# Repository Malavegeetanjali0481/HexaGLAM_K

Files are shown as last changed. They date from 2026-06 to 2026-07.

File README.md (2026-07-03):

## 1)🚶 Hexapod Walking

The walking function enables the hexapod robot to move forward using a tripod gait, where three legs move while the other three remain on the ground for support. This gait provides excellent stability, smooth movement, and balanced weight distribution, allowing the robot to navigate different surfaces efficiently while maintaining continuous balance.

Walking Demo Video : https://github.com/Malavegeetanjali0481/HexaGLAM_K/issues/1

## 2)💃 Hexapod Dancing

The dancing function demonstrates the robot's coordinated servo movements by executing a sequence of rhythmic leg motions. The programmed dance routine synchronizes all six legs to create smooth and visually appealing movements, showcasing the precision of the inverse kinematics and servo control system while highlighting the robot's flexibility and stability.

 Dancing Demo Video : https://github.com/Malavegeetanjali0481/HexaGLAM_K/issues/2
 
## 3)📱 HexaGlAM_K Mobile Application Development

The HexaGlAM_K mobile application was developed using MIT App Inventor to provide an intuitive interface for controlling and monitoring the ESP32-based Hexapod Robot. The application consists of multiple screens, each designed for a specific functionality, making robot operation simple and user-friendly.

### Step 1: Designing the Home Screen

The development began by creating the Home Screen, which serves as the application's landing page. A clean and attractive user interface was designed with the project title, robot image/logo, and navigation buttons. This screen allows users to easily access different modules of the application such as Robot Control, Sensor Dashboard, Camera Monitoring, and About sections. Proper alignment, icons, and color themes were chosen to enhance the overall user experience.

### Step 2: Developing the Robot Control Screen

A dedicated Control Screen was developed to operate the Hexapod robot remotely. Large control buttons were added to send Bluetooth commands to the ESP32. Each button transmits a predefined command that controls the robot's movements.

The implemented control functions include:
<ul>
  <li>Stand</li>
   <li>Walk</li>
   <li>Dance</li>
   <li>Halt</li>

</ul>

### Step 3: Creating the Sensor Dashboard

A Sensor Dashboard was developed to display real-time environmental data collected by the sensors connected to the ESP32. The dashboard retrieves data from the ThingSpeak cloud platform and presents all sensor readings on a single screen.
Each sensor value is displayed inside individual cards with appropriate labels, making the dashboard easy to understand and monitor.
### These are the Screens of app:
<table>
  <tr>
    <td >
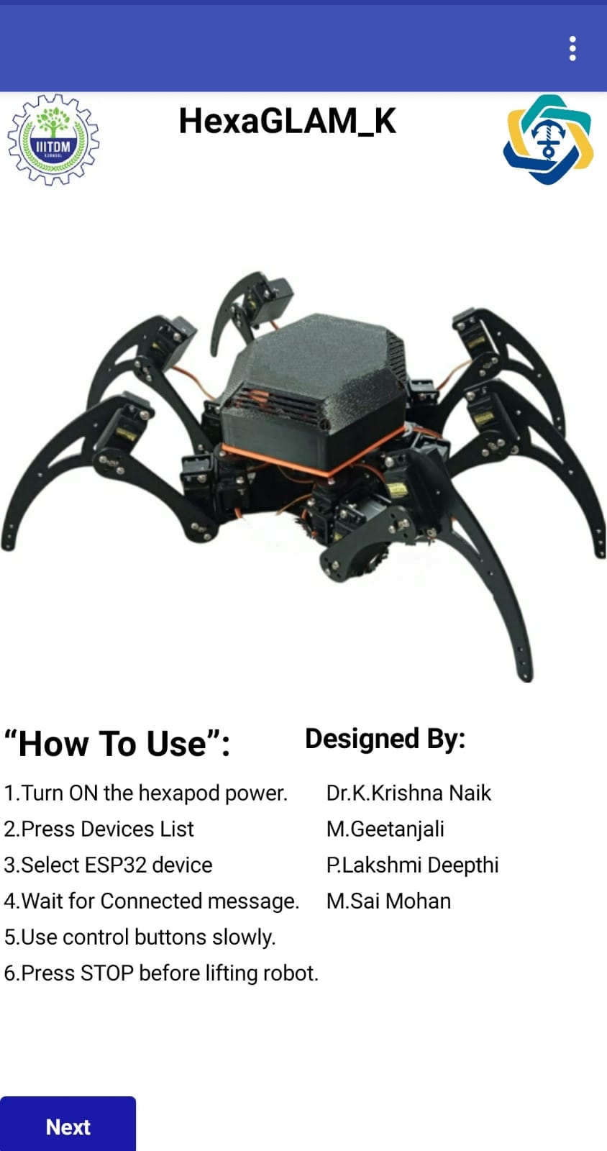
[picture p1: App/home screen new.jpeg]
Home Screen
       
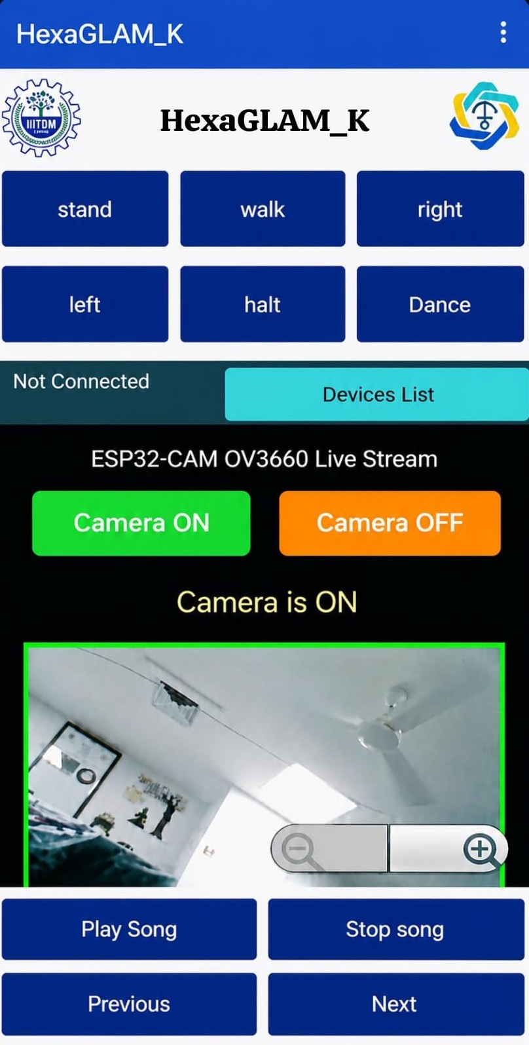
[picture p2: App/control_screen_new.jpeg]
   
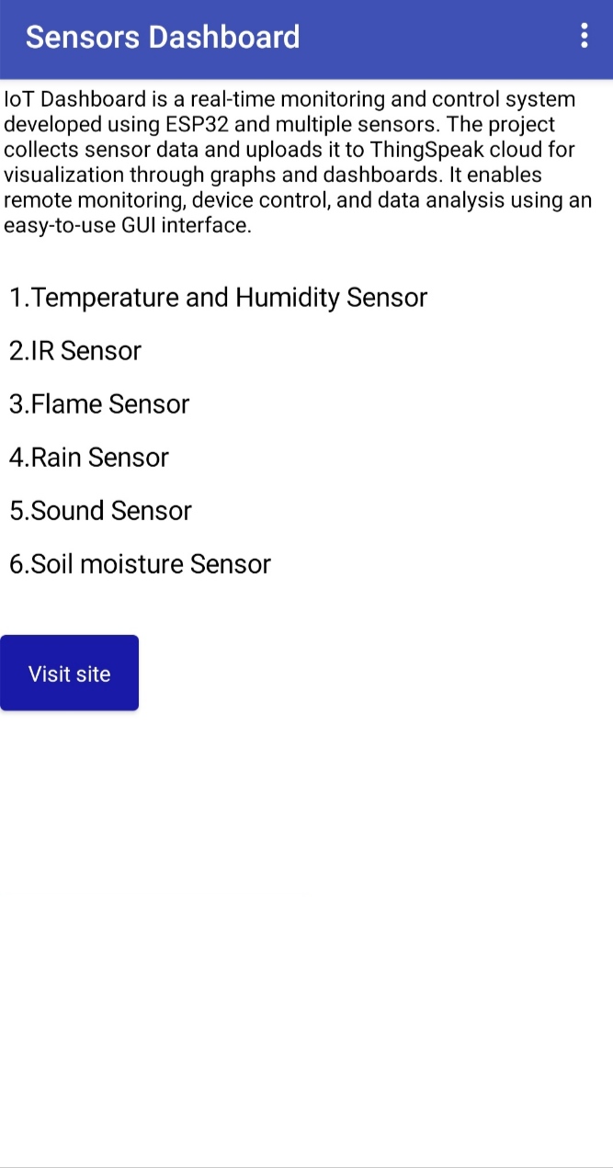
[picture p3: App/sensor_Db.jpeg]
    
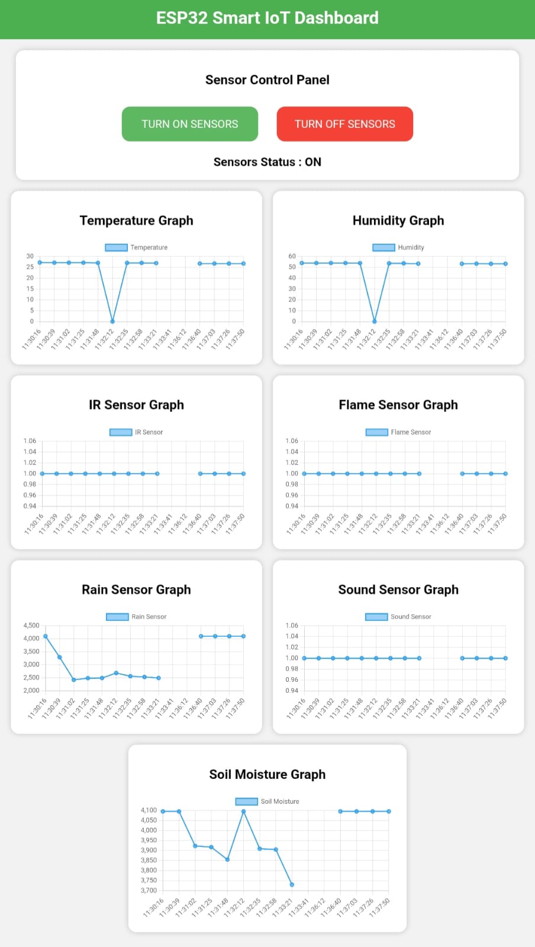
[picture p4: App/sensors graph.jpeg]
     
    </td>
  </tr>
</table>

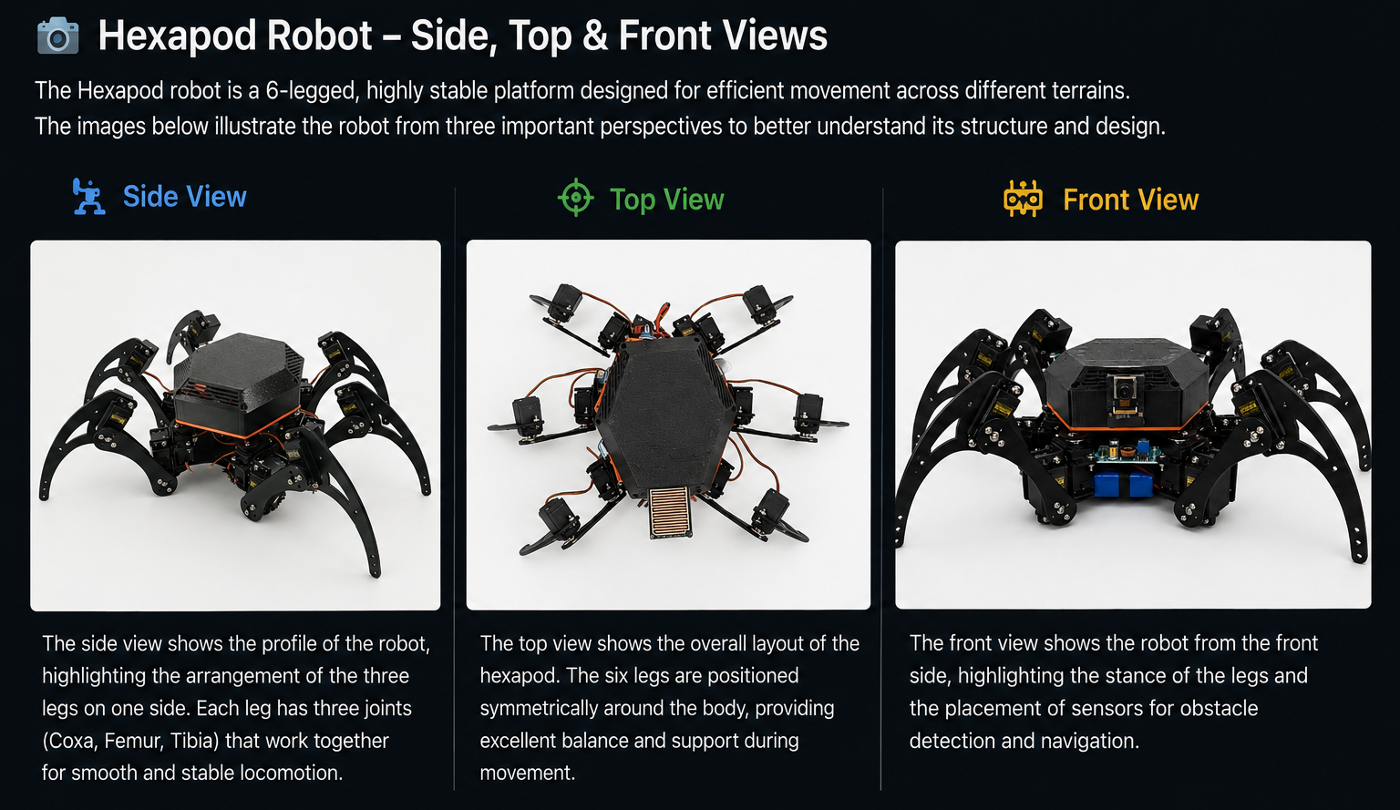
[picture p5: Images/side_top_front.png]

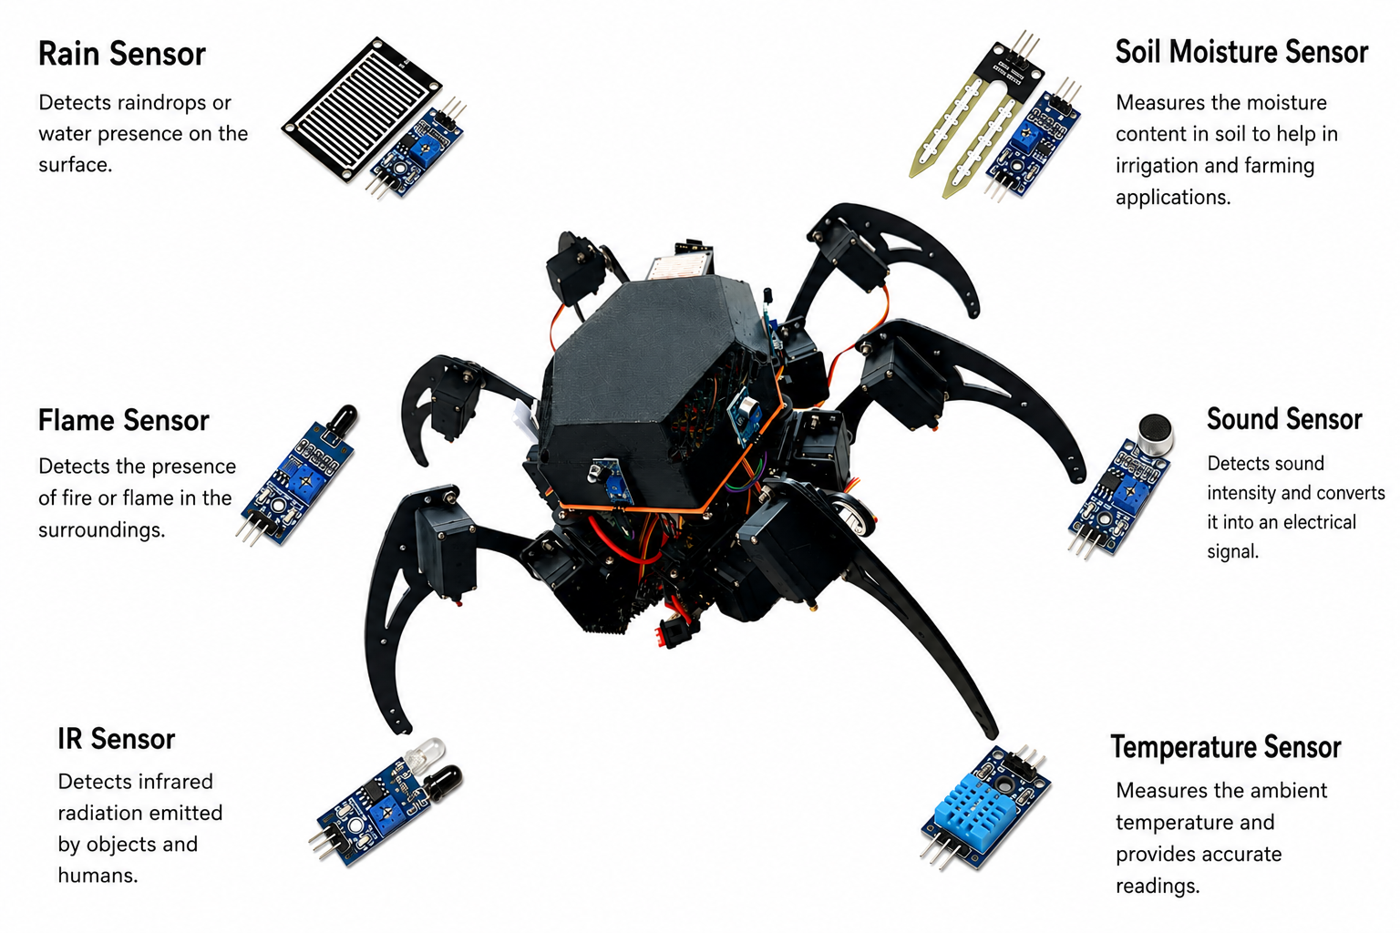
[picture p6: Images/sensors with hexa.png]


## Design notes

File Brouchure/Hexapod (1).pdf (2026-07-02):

# Market analysis

# Implementation strategy

# HEXAPOD WITH

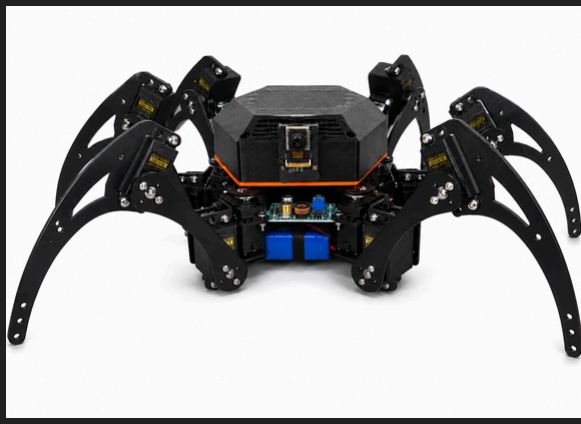
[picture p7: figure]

# SENSORS

## The global market for hexapod robots is growing rapidly across defense, industrial

inspection, agriculture, healthcare, research,

## and disaster response, driven by advancements in robotics, IoT, AI, and

automation.

## The hexapod robot was implemented by

designing the mechanical structure,

## interfacing 18 servo motors with an ESP32 through PCA9685 servo drivers, and integrating sensors for real-time data collection. A Bluetooth-based mobile app was developed for robot control

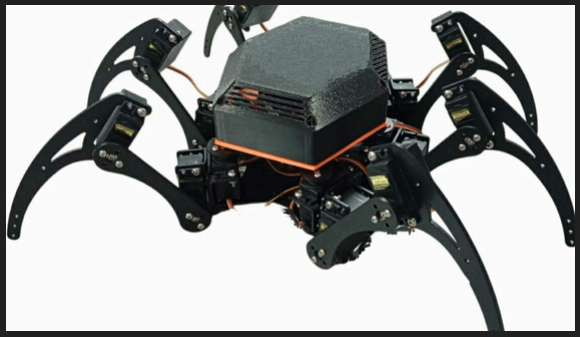
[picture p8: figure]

# Project goals and objectives

## This project presents a Hexapod Robot built using an ESP32 microcontroller and an 18-servo locomotion system. The robot is designed to achieve stable movement

using a six-legged walking mechanism,

## making it suitable for navigating uneven

terrain while maintaining balance.

# Welcome!

# HexaGLAM_K App

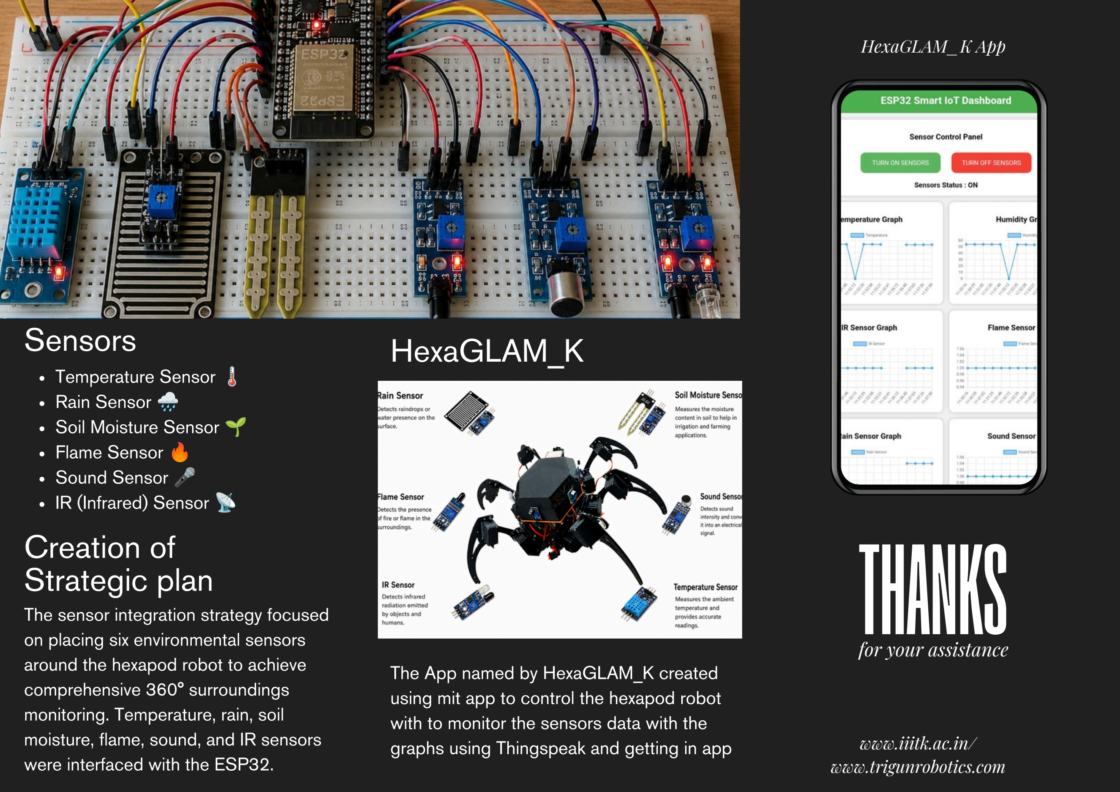
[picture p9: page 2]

# THANKS

The sensor integration strategy focused

on placing six environmental sensors

around the hexapod robot to achieve

comprehensive 360° surroundings

monitoring. Temperature, rain, soil

moisture, flame, sound, and IR sensors

were interfaced with the ESP32.

# Sensors

# Creation of Strategic plan

Temperature Sensor | ️
Rain Sensor | ️
Soil Moisture Sensor 🌱

Flame Sensor 🔥

Sound Sensor 🎤

IR (Infrared) Sensor 📡

# HexaGLAM

_

K

The App named by HexaGLAM_K created

using mit app to control the hexapod robot

with to monitor the sensors data with the

graphs using Thingspeak and getting in app

# for your assistance

# www.iiitk.ac.in/ www.trigunrobotics.com

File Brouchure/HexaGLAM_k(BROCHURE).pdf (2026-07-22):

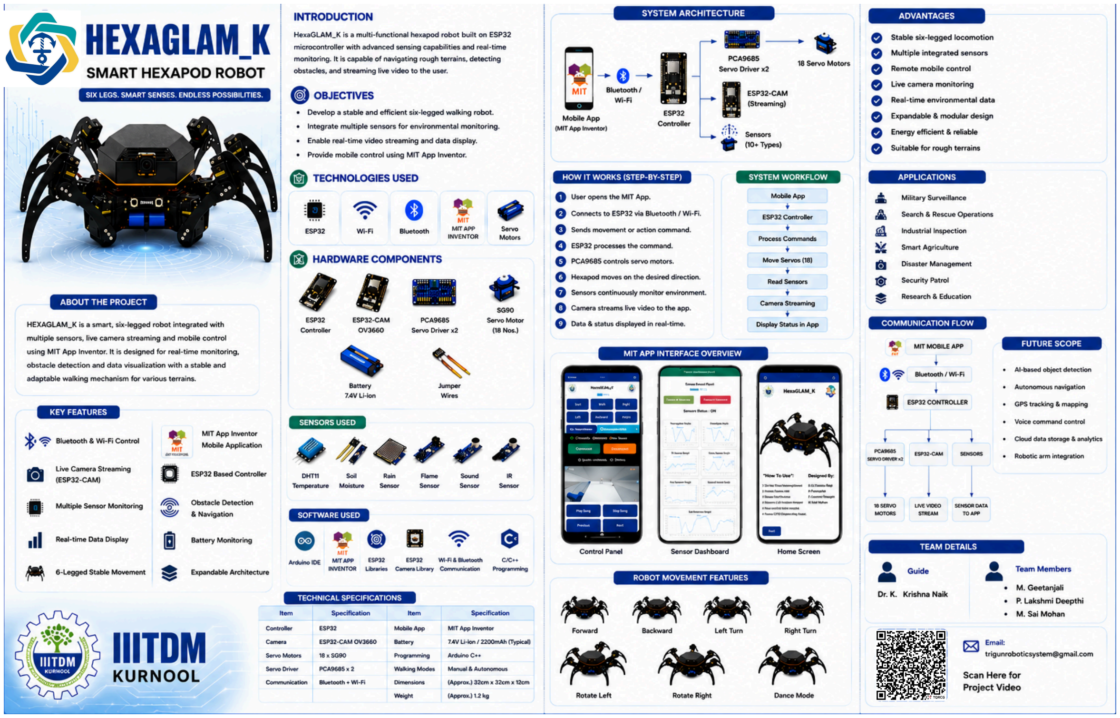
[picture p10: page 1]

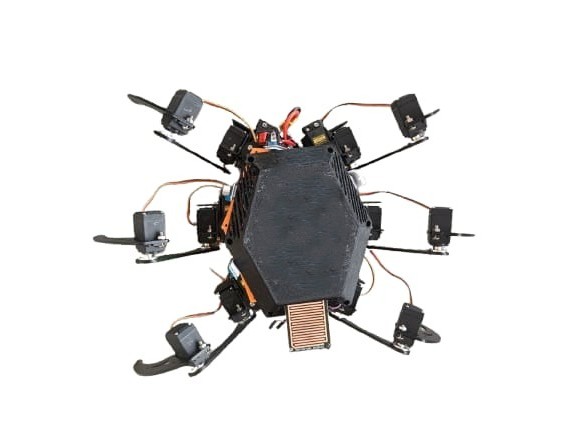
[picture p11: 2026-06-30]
Images/top_view.jpeg

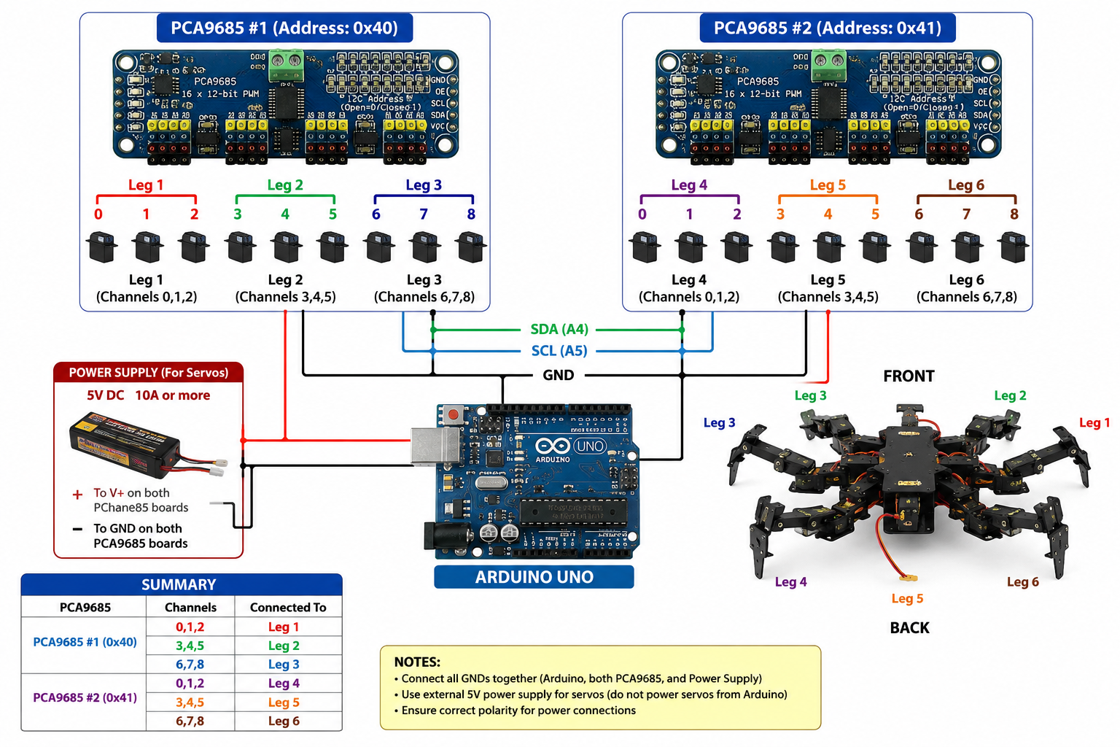
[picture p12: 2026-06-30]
Images/pca connections ant.png

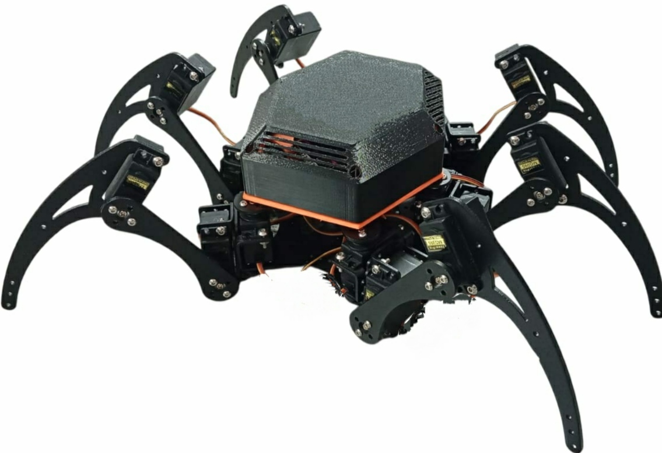
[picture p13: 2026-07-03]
Images/zoom hexapod.jpeg

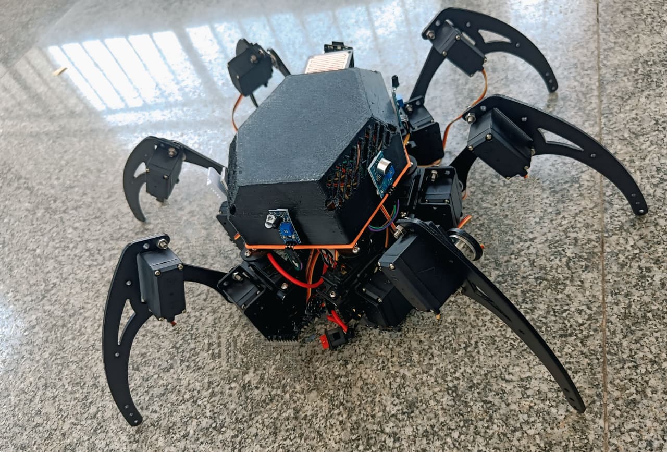
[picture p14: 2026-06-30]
Images/sen___ss.jpeg

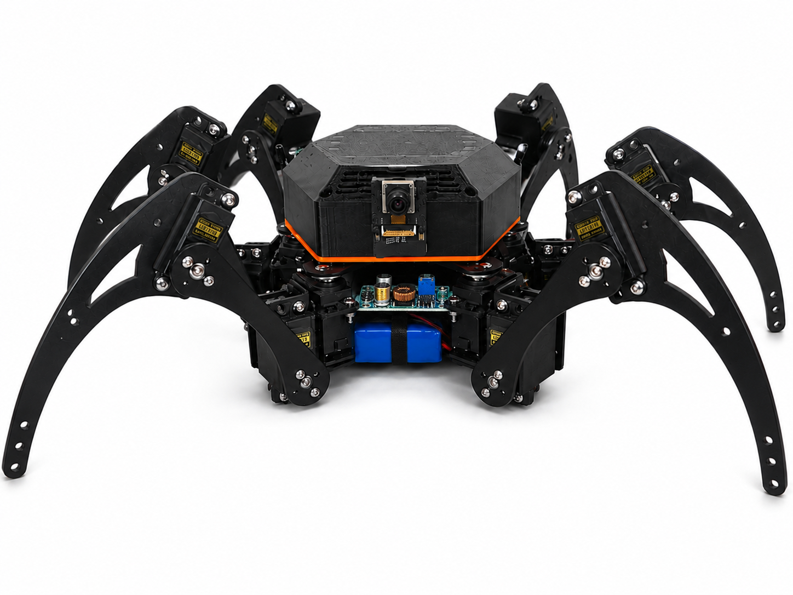
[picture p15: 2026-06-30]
Images/Front view.png

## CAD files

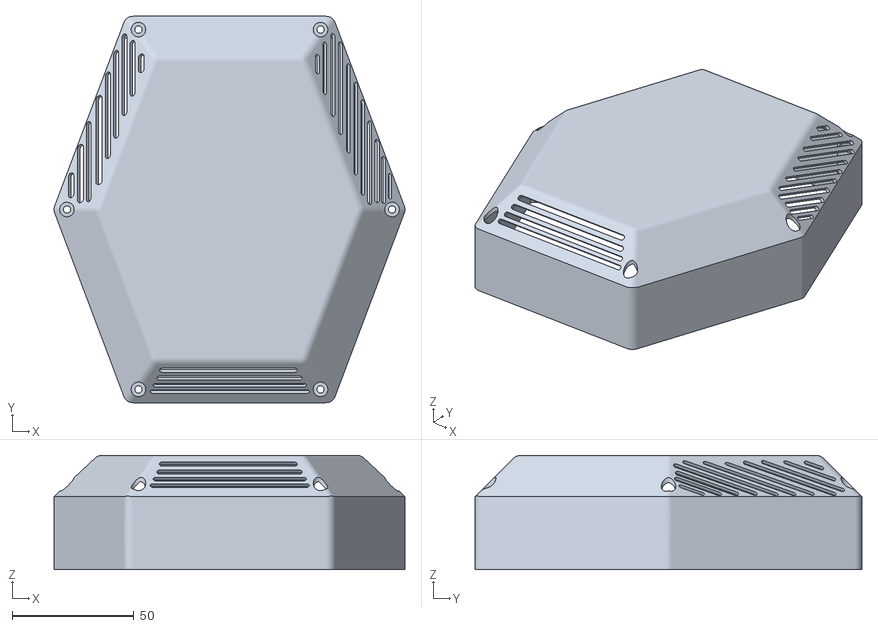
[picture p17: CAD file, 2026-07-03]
Dimension/Part Studio 1 - Top.stl
144.4 x 159.1 x 47.0

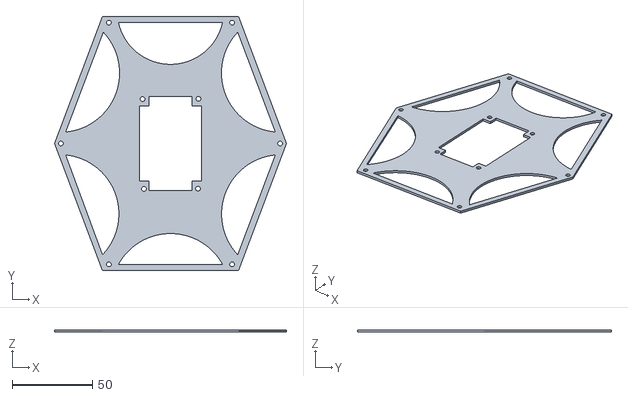
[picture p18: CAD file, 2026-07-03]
Dimension/Part Studio 2 - Base.stl
145.0 x 159.1 x 1.50

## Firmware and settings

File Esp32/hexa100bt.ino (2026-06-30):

#include <Wire.h>
#include <Adafruit_PWMServoDriver.h>

// =====================================================
// BLUETOOTH SUPPORT ADDED
// =====================================================
#include "BluetoothSerial.h"
BluetoothSerial SerialBT;

// =====================================================
// HEXAPOD ROBOT (ESP32 VERSION)
// Logic unchanged from Nano version
// =====================================================

// ------------------- CONFIG -------------------
#define SERVO_FREQ 60

// ESP32 I2C PINS
#define SDA_PIN 21
#define SCL_PIN 22

// ------------------- GAIT PARAMETERS -------------------
float gaitCycleTime = 1600;
float stanceRatio   = 0.65;

// Motion amplitudes
float coxaAmplitude = 15;
float femurLift     = 15;
float tibiaLift     = 8;

// Servo safety limits
int minAngle = 40;
int maxAngle = 150;

// ------------------- JOINT DEFINITIONS -------------------
#define COXA  0
#define FEMUR 1
#define TIBIA 2

// ------------------- LEG DEFINITIONS -------------------
#define FL 0
#define ML 1
#define RL 2
#define FR 3
#define MR 4
#define RR 5

// ------------------- SERVO MAPPING -------------------
int servoIndex[6][3] = {

  {0, 1, 2},
  {3, 4, 5},
  {6, 7, 8},

  {9, 10, 11},
  {12, 13, 14},
  {15, 16, 17}
};

// ------------------- NEUTRAL POSITIONS -------------------
int neutralAngle[6][3] = {

  {130, 70, 70},
  {90, 70, 70},
  {70, 70, 70},

  {70, 105, 130},
  {90, 105, 110},
  {120, 110, 130}
};

// ------------------- INVERSION FLAGS -------------------
int invCoxa[6]  = {-1, -1, -1,  1,  1,  1};

int invFemur[6] = {
   1,  1,  1,
  -1, -1, -1
};

int invTibia[6] = {
   1,  1,  1,
  -1, -1, -1
};

// =====================================================
// PCA9685 OBJECTS
// =====================================================

Adafruit_PWMServoDriver pwm1 = Adafruit_PWMServoDriver(0x40);
Adafruit_PWMServoDriver pwm2 = Adafruit_PWMServoDriver(0x41);

float usPerTick;

// =====================================================
// CONTROL MODES
// =====================================================

enum Mode {
  STAND,
  WALK,
  HALT
};

Mode mode = STAND;

// =====================================================
// TIMERS
// =====================================================

unsigned long gaitStartTime = 0;
unsigned long lastUpdate = 0;

// =====================================================
// UTILITY FUNCTIONS
// =====================================================

uint16_t usToTicks(uint16_t us) {

  float ticks = us / usPerTick;

  if (ticks < 0) ticks = 0;
  if (ticks > 4095) ticks = 4095;

  return (uint16_t)(ticks + 0.5f);
}

// Convert angle -> microseconds
uint16_t angleToUs(int angle) {

  return map(angle, 0, 180, 480, 2120);
}

// =====================================================
// SERVO OUTPUT
// =====================================================

void setServoAngle(int servo, int angle) {

  angle = constrain(angle, minAngle, maxAngle);

  uint16_t us = angleToUs(angle);
  uint16_t ticks = usToTicks(us);

  // PCA BOARD #1
  if (servo < 16) {

    pwm1.setPWM(servo, 0, ticks);
  }

  // PCA BOARD #2
  else {

    pwm2.setPWM(servo - 16, 0, ticks);
  }
}

// =====================================================
// GAIT MATH
// =====================================================

// Smooth lift curve
float liftShape(float local) {

  return sin(local * PI);
}

// Coxa motion
float coxaOffset(float phase) {

  // STANCE
  if (phase < stanceRatio) {

    float local = phase / stanceRatio;

    return -coxaAmplitude * cos(local * PI);
  }

  // SWING
  else {

    float local = (phase - stanceRatio) / (1.0 - stanceRatio);

    return coxaAmplitude * cos(local * PI);
  }
}

// Femur lift
float femurOffset(float phase) {

  if (phase < stanceRatio) {
    return 0;
  }

  float local = (phase - stanceRatio) / (1.0 - stanceRatio);

  return femurLift * liftShape(local);
}

// Tibia lift
float tibiaOffset(float phase) {

  if (phase < stanceRatio) {
    return 0;
  }

  float local = (phase - stanceRatio) / (1.0 - stanceRatio);

  return tibiaLift * liftShape(local);
}

// =====================================================
// PHASE FUNCTIONS
// =====================================================

// Tripod phase assignment
float legPhase(int leg, float globalPhase) {

  bool tripodA =
    (leg == FL || leg == MR || leg == RL);

  float p = globalPhase;

  // Tripod B shift
  if (!tripodA) {
    p += 0.5;
  }

  if (p >= 1.0) {
    p -= 1.0;
  }

  return p;
}

// =====================================================
// ANGLE COMPUTATION
// =====================================================

float computeAngle(int leg, int joint, float phase) {

  float offset = 0;

  // COXA
  if (joint == COXA) {

    offset =
      coxaOffset(phase) *
      invCoxa[leg];
  }

  // FEMUR
  if (joint == FEMUR) {

    offset =
      femurOffset(phase) *
      invFemur[leg];
  }

  // TIBIA
  if (joint == TIBIA) {

    offset =
      tibiaOffset(phase) *
      invTibia[leg];
  }

  return neutralAngle[leg][joint] + offset;
}

// =====================================================
// POSES
// =====================================================

void standPose() {

  for (int leg = 0; leg < 6; leg++) {

    for (int joint = 0; joint < 3; joint++) {

      setServoAngle(
        servoIndex[leg][joint],
        neutralAngle[leg][joint]
      );
    }
  }
}

// =====================================================
// WALKING
// =====================================================

void walkCycle() {

  float cycle =
    (millis() - gaitStartTime) %
    (unsigned long)gaitCycleTime;

  float globalPhase =
    cycle / gaitCycleTime;

  // Update all legs
  for (int leg = 0; leg < 6; leg++) {

    float phase =
      legPhase(leg, globalPhase);

    for (int joint = 0; joint < 3; joint++) {

      int angle =
        computeAngle(
          leg,
          joint,
          phase
        );

      setServoAngle(
        servoIndex[leg][joint],
        angle
      );
    }
  }
}

// =====================================================
// SERIAL + BLUETOOTH COMMANDS
// =====================================================

void handleSerial() {

  String cmd = "";

  // ---------------- SERIAL INPUT ----------------
  if (Serial.available()) {

    cmd =
      Serial.readStringUntil('\n');

    cmd.trim();
  }

  // -------------- BLUETOOTH INPUT ---------------
  else if (SerialBT.available()) {

    cmd =
      SerialBT.readStringUntil('\n');

    cmd.trim();
  }

  else {
    return;
  }

  // ---------------- STAND ----------------
  if (cmd == "s" || cmd == "stand") {

    mode = STAND;

    standPose();

    Serial.println("Mode: STAND");
    SerialBT.println("Mode: STAND");
  }

  // ---------------- WALK ----------------
  else if (cmd == "w" || cmd == "walk") {

    gaitStartTime = millis();

    mode = WALK;

    Serial.println("Mode: WALK");
    SerialBT.println("Mode: WALK");
  }

  // ---------------- HALT ----------------
  else if (cmd == "h" || cmd == "halt") {

    mode = HALT;

    Serial.println("Mode: HALT");
    SerialBT.println("Mode: HALT");
  }

  // ---------------- SPEED ----------------
  else if (cmd.startsWith("speed ")) {

    int value =
      cmd.substring(6).toInt();

    if (value > 200) {

      gaitCycleTime = value;

      Serial.print("Cycle Time: ");
      Serial.println(gaitCycleTime);

      SerialBT.print("Cycle Time: ");
      SerialBT.println(gaitCycleTime);
    }
  }

  // ---------------- STRIDE ----------------
  else if (cmd.startsWith("stride ")) {

    int value =
      cmd.substring(7).toInt();

    coxaAmplitude = value;

    Serial.print("Stride: ");
    Serial.println(coxaAmplitude);

    SerialBT.print("Stride: ");
    SerialBT.println(coxaAmplitude);
  }

  // ---------------- FEMUR ----------------
  else if (cmd.startsWith("lift ")) {

    int value =
      cmd.substring(5).toInt();

    femurLift = value;

    Serial.print("Femur Lift: ");
    Serial.println(femurLift);

    SerialBT.print("Femur Lift: ");
    SerialBT.println(femurLift);
  }

  // ---------------- TIBIA ----------------
  else if (cmd.startsWith("knee ")) {

    int value =
      cmd.substring(5).toInt();

    tibiaLift = value;

    Serial.print("Tibia Lift: ");
    Serial.println(tibiaLift);

    SerialBT.print("Tibia Lift: ");
    SerialBT.println(tibiaLift);
  }
}

// =====================================================
// SETUP
// =====================================================

void setup() {

  Serial.begin(115200);

  // =====================================================
  // BLUETOOTH START
  // =====================================================
  SerialBT.begin("ESP32_HEXAPOD");

  // ESP32 I2C START
  Wire.begin(SDA_PIN, SCL_PIN);

  // PCA #1
  pwm1.begin();
  pwm1.setPWMFreq(SERVO_FREQ);

  // PCA #2
  pwm2.begin();
  pwm2.setPWMFreq(SERVO_FREQ);

  // Tick conversion
  float periodUs =
    1000000.0 / SERVO_FREQ;

  usPerTick =
    periodUs / 4096.0;

  delay(500);

  standPose();

  Serial.println();
  Serial.println("=================================");
  Serial.println(" HEXAPOD READY (ESP32) ");
  Serial.println("=================================");
  Serial.println("Commands:");
  Serial.println("s / stand");
  Serial.println("w / walk");
  Serial.println("h / halt");
  Serial.println("speed <ms>");
  Serial.println("stride <deg>");
  Serial.println("lift <deg>");
  Serial.println("knee <deg>");
  Serial.println("=================================");

  // Bluetooth startup message
  SerialBT.println();
  SerialBT.println("=================================");
  SerialBT.println(" HEXAPOD READY (ESP32) ");
  SerialBT.println("=================================");
  SerialBT.println("Bluetooth Name: ESP32_HEXAPOD");
  SerialBT.println("Commands:");
  SerialBT.println("s / stand");
  SerialBT.println("w / walk");
  SerialBT.println("h / halt");
  SerialBT.println("speed <ms>");
  SerialBT.println("stride <deg>");
  SerialBT.println("lift <deg>");
  SerialBT.println("knee <deg>");
  SerialBT.println("=================================");
}

// =====================================================
// MAIN LOOP
// =====================================================

void loop() {

  handleSerial();

  unsigned long now = millis();

  // 50Hz update loop
  if (now - lastUpdate >= 20) {

    lastUpdate = now;

    if (mode == WALK) {

      walkCycle();
    }
  }
}

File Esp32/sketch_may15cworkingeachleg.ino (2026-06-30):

#include <Wire.h>
#include <Adafruit_PWMServoDriver.h>

// =====================================================
// HEXAPOD ROBOT
// Arduino UNO + 2 PCA9685
// ALL 6 LEGS WALKING
// =====================================================

// PCA9685 Boards
Adafruit_PWMServoDriver pca1 = Adafruit_PWMServoDriver(0x40);
Adafruit_PWMServoDriver pca2 = Adafruit_PWMServoDriver(0x41);

// =====================================================
// SERVO SETTINGS
// =====================================================

#define SERVOMIN 110
#define SERVOMAX 490

// =====================================================
// WALK CONTROL
// =====================================================

bool walking = false;

// =====================================================
// ANGLE TO PWM
// =====================================================

int angleToPulse(int ang)
{
  return map(ang, 0, 180, SERVOMIN, SERVOMAX);
}

// =====================================================
// MOVE SERVO
// =====================================================

void setServo(Adafruit_PWMServoDriver &pca, int channel, int angle)
{
  angle = constrain(angle, 30, 150);

  int pulse = angleToPulse(angle);

  pca.setPWM(channel, 0, pulse);
}

// =====================================================
// STAND POSITION
// =====================================================

void standPosition()
{
  // PCA1
  for (int ch = 0; ch <= 8; ch++)
  {
    setServo(pca1, ch, 90);
  }

  // PCA2
  for (int ch = 0; ch <= 8; ch++)
  {
    setServo(pca2, ch, 90);
  }

  delay(1000);
}

// =====================================================
// MOVE ONE LEG
// =====================================================

void moveLeg(
  Adafruit_PWMServoDriver &pca,
  int coxa,
  int femur,
  int tibia,
  int dir)
{
  // ===================================
  // LIFT LEG
  // ===================================

  for (int a = 90; a >= 65; a--)
  {
    setServo(pca, femur, a);

    delay(4);
  }

  // ===================================
  // FORWARD SWING
  // ===================================

  if (dir == 1)
  {
    for (int a = 70; a <= 120; a++)
    {
      setServo(pca, coxa, a);

      delay(4);
    }
  }
  else
  {
    for (int a = 120; a >= 70; a--)
    {
      setServo(pca, coxa, a);

      delay(4);
    }
  }

  // ===================================
  // LOWER LEG
  // ===================================

  for (int a = 65; a <= 90; a++)
  {
    setServo(pca, femur, a);

    delay(4);
  }

  // ===================================
  // PUSH BODY
  // ===================================

  if (dir == 1)
  {
    for (int a = 120; a >= 70; a--)
    {
      setServo(pca, coxa, a);

      delay(4);
    }
  }
  else
  {
    for (int a = 70; a <= 120; a++)
    {
      setServo(pca, coxa, a);

      delay(4);
    }
  }
}

// =====================================================
// TRIPOD GAIT WALK
// =====================================================

void tripodWalk()
{
  // ===================================
  // GROUP A
  // LEG 1,3,5
  // ===================================

  moveLeg(pca1, 0, 1, 2, 1); // LEG 1

  moveLeg(pca1, 6, 7, 8, 1); // LEG 3

  moveLeg(pca2, 3, 4, 5, 1); // LEG 5

  delay(20);

  // ===================================
  // GROUP B
  // LEG 2,4,6
  // ===================================

  moveLeg(pca1, 3, 4, 5, 0); // LEG 2

  moveLeg(pca2, 0, 1, 2, 0); // LEG 4

  moveLeg(pca2, 6, 7, 8, 0); // LEG 6

  delay(20);
}

// =====================================================
// WALK LONG DISTANCE
// =====================================================

void walkDistance()
{
  for (int i = 0; i < 80; i++)
  {
    tripodWalk();
  }
}

// =====================================================
// SETUP
// =====================================================

void setup()
{
  Serial.begin(9600);

  Serial.println("HEXAPOD STARTING");

  // PCA START
  pca1.begin();
  pca2.begin();

  pca1.setPWMFreq(50);
  pca2.setPWMFreq(50);

  delay(1000);

  // INITIAL POSITION
  standPosition();

  Serial.println("READY");

  Serial.println("Commands:");
  Serial.println("s = START WALK");
  Serial.println("x = STOP");
  Serial.println("w = WALK DISTANCE");
}

// =====================================================
// LOOP
// =====================================================

void loop()
{
  // ===================================
  // SERIAL COMMANDS
  // ===================================

  if (Serial.available())
  {
    char cmd = Serial.read();

    // START CONTINUOUS WALK
    if (cmd == 's')
    {
      walking = true;

      Serial.println("WALKING...");
    }

    // STOP
    else if (cmd == 'x')
    {
      walking = false;

      standPosition();

      Serial.println("STOPPED");
    }

    // WALK DISTANCE
    else if (cmd == 'w')
    {
      Serial.println("WALKING LONG DISTANCE");

      walkDistance();

      Serial.println("DONE");
    }
  }

  // CONTINUOUS WALK
  if (walking)
  {
    tripodWalk();
  }
}

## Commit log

2026-07-03 Update image source for sensor screen in README
    Replaced an image source in the README with a new sensor database image.
2026-07-03 Adjust image size for sensors with Hexa
    Updated image dimensions for sensors with Hexa.
2026-07-03 Adjust image size for sensors with Hexa
    Updated image size for sensors with Hexa.
